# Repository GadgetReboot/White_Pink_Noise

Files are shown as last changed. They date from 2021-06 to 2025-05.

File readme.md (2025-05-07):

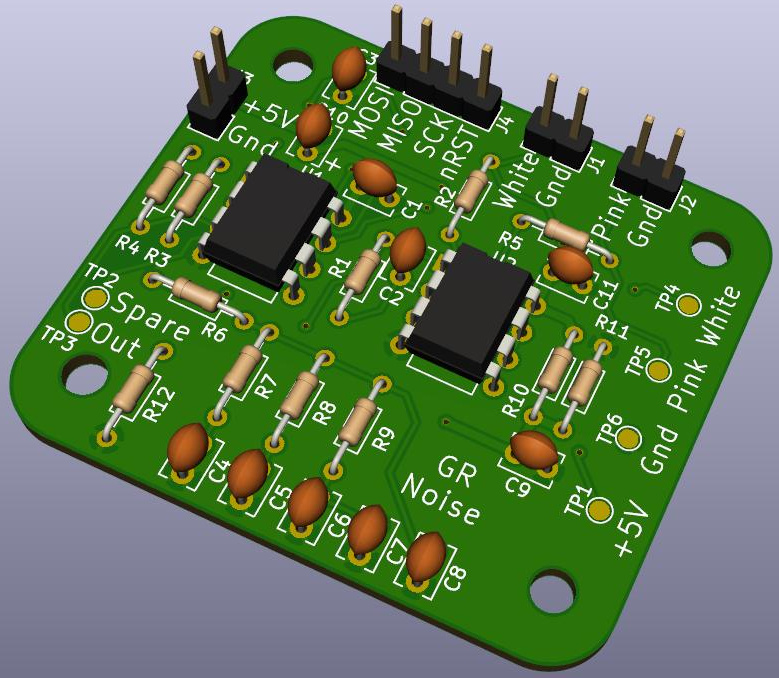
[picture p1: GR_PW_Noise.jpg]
<BR><BR><BR>
White and Pink noise generating PCB<BR>
Uses a linear feedback shift register in an ATTiny85 to generate pseudo random white noise<BR>
Then uses a -3 dB/octave low pass RC filter to convert to pink noise.<BR>
ATTiny Sketch: https://github.com/GadgetReboot/White_Noise_LFSR

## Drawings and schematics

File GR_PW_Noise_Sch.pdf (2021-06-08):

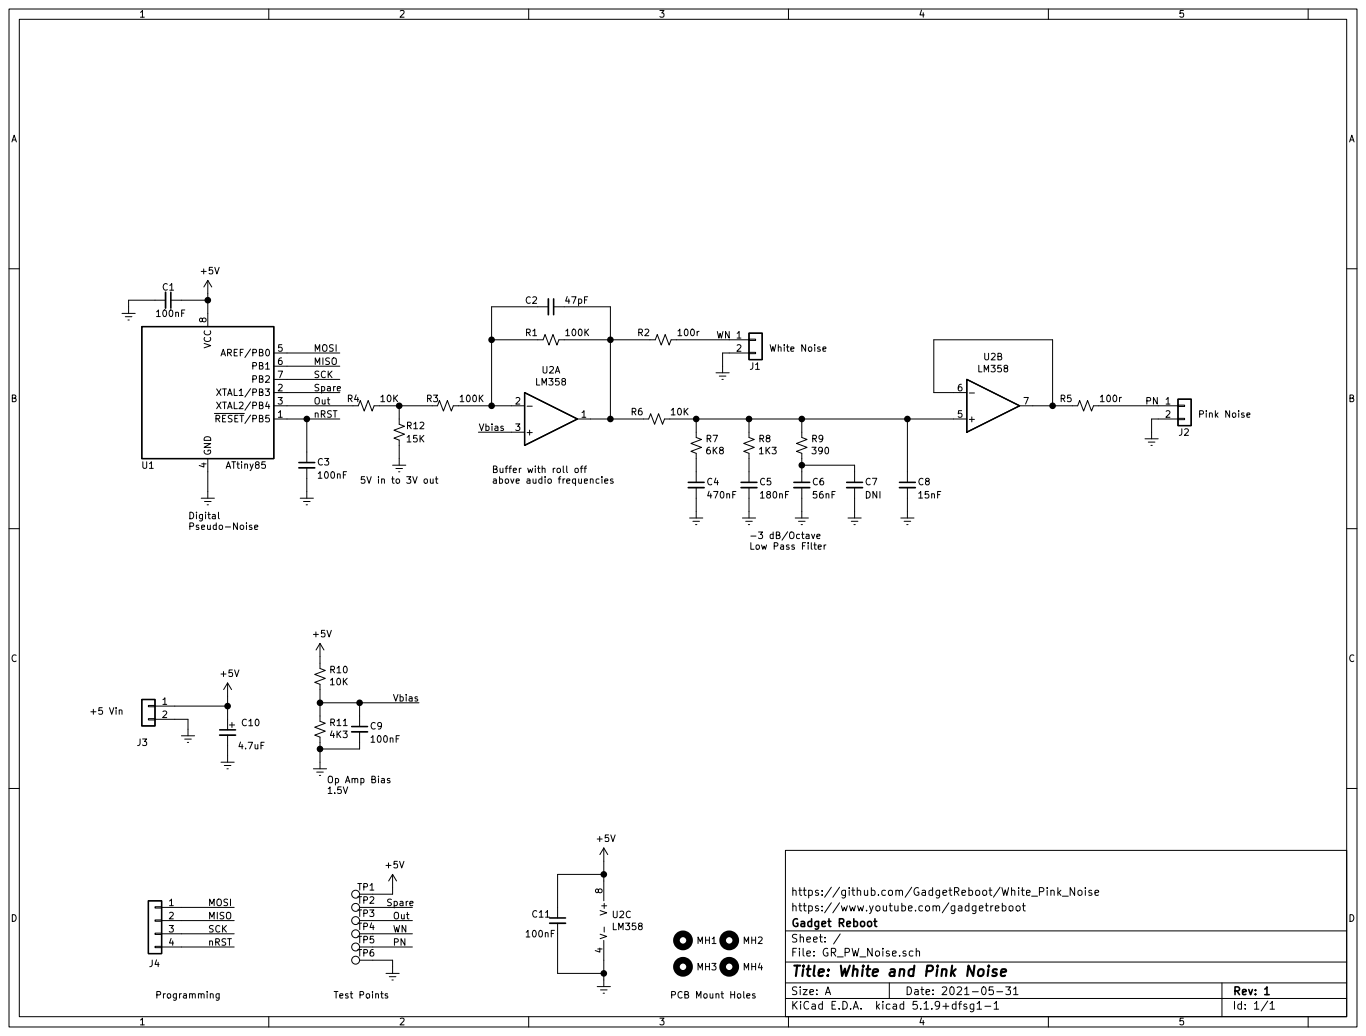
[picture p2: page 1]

PCB Mount Holes +5 Vin

https://github.com/GadgetReboot/White_Pink_Noise
https://www.youtube.com/gadgetreboot
File: GR_PW_Noise.sch Sheet: / Gadget Reboot

Id: 1/1 Title: White and Pink Noise

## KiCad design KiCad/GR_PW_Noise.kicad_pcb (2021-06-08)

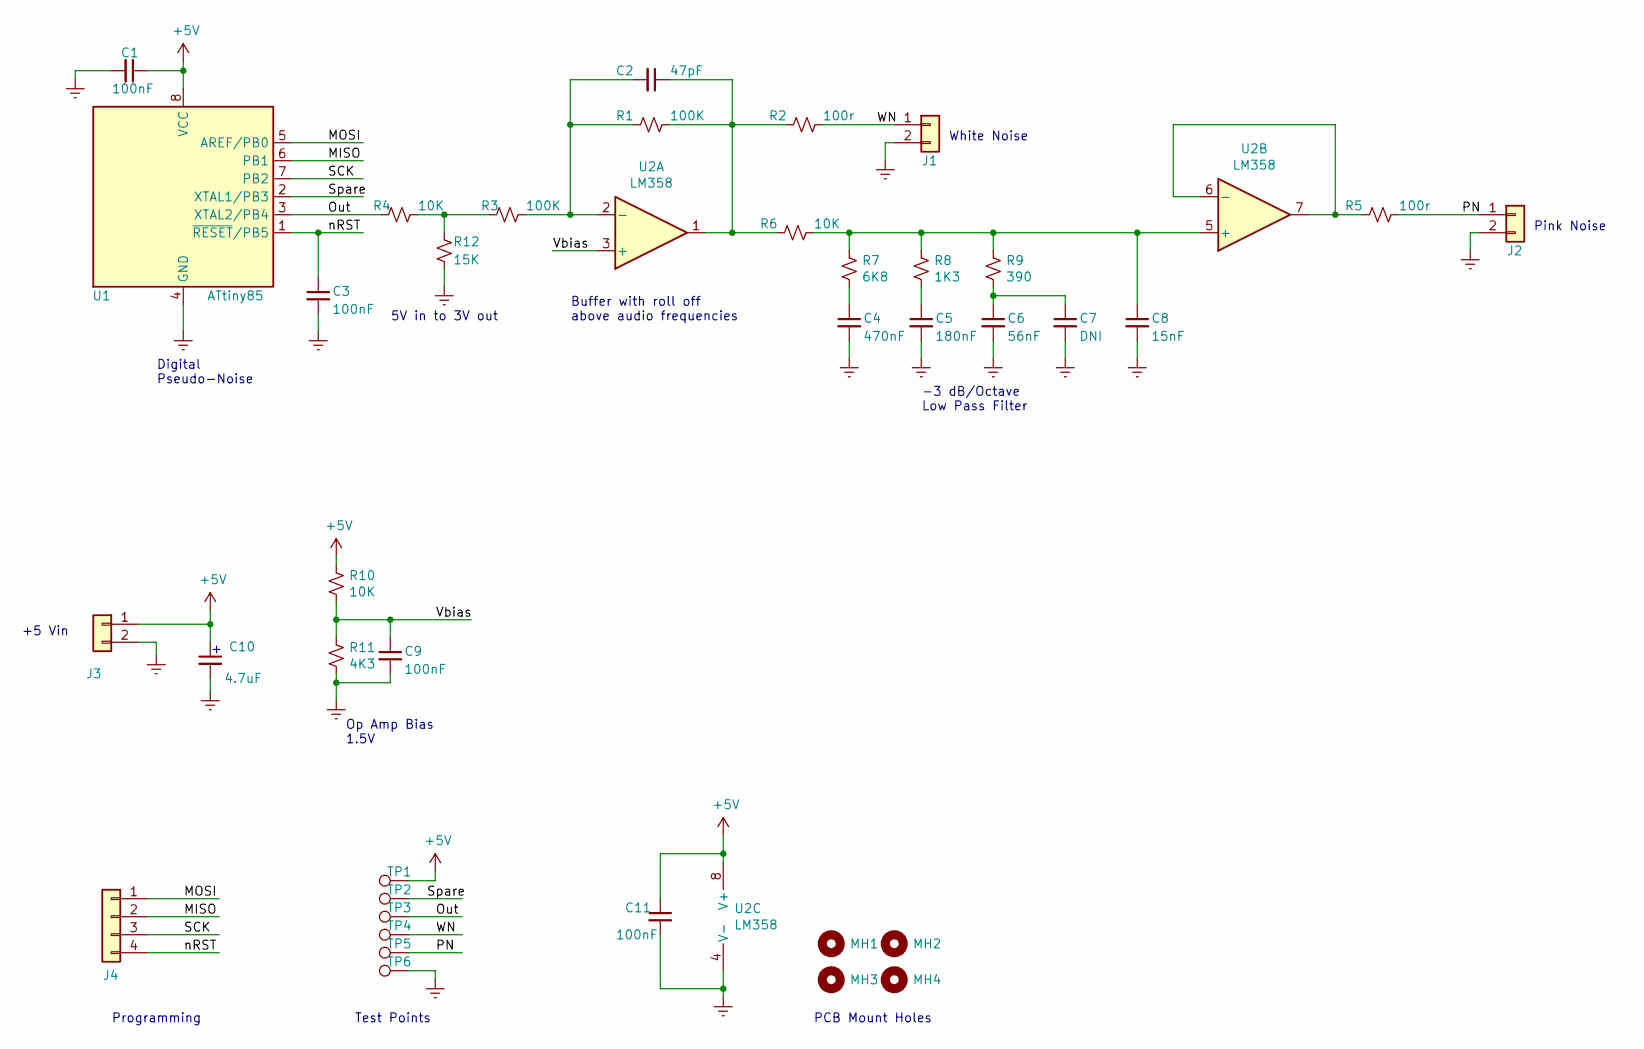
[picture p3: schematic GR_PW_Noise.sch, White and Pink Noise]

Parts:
C1, C3, C9, C11: 100nF; C_Disc_D3.8mm_W2.6mm_P2.50mm
C2: 47pF; C_Disc_D3.8mm_W2.6mm_P2.50mm
C4: 470nF; C_Disc_D3.8mm_W2.6mm_P2.50mm
C5: 180nF; C_Disc_D3.8mm_W2.6mm_P2.50mm
C6: 56nF; C_Disc_D3.8mm_W2.6mm_P2.50mm
C7: DNI; C_Disc_D3.8mm_W2.6mm_P2.50mm
C8: 15nF; C_Disc_D3.8mm_W2.6mm_P2.50mm
C10: 4.7uF; C_Disc_D3.8mm_W2.6mm_P2.50mm
J1, J2, J3: Conn_01x02; PinHeader_1x02_P2.54mm_Vertical
J4: Conn_01x04; PinHeader_1x04_P2.54mm_Vertical
MH1, MH2, MH3, MH4: MountingHole; MountingHole_3.2mm_M3
R1, R3: 100K; R_Axial_DIN0204_L3.6mm_D1.6mm_P7.62mm_Horizontal
R2, R5: 100r; R_Axial_DIN0204_L3.6mm_D1.6mm_P7.62mm_Horizontal
R4, R6, R10: 10K; R_Axial_DIN0204_L3.6mm_D1.6mm_P7.62mm_Horizontal
R7: 6K8; R_Axial_DIN0204_L3.6mm_D1.6mm_P7.62mm_Horizontal
R8: 1K3; R_Axial_DIN0204_L3.6mm_D1.6mm_P7.62mm_Horizontal
R9: 390; R_Axial_DIN0204_L3.6mm_D1.6mm_P7.62mm_Horizontal
R11: 4K3; R_Axial_DIN0204_L3.6mm_D1.6mm_P7.62mm_Horizontal
R12: 15K; R_Axial_DIN0204_L3.6mm_D1.6mm_P7.62mm_Horizontal
TP1, TP2, TP3, TP4, TP5, TP6: TestPoint; TestPoint_Pad_D1.5mm
U1: ATtiny85; DIP-8_W7.62mm
U2: LM358; DIP-8_W7.62mm

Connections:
+5V: C1.1, C10.1, C11.1, J3.1, R10.2, TP1.1, U1.8 (VCC), U2.8 (V+)
/MISO: J4.2, U1.6 (PB1)
/MOSI: J4.1, U1.5 (AREF/PB0)
/Out: R4.1, TP3.1, U1.3 (XTAL2/PB4)
/PN: J2.1, R5.2, TP5.1
/SCK: J4.3, U1.7 (PB2)
/Spare: TP2.1, U1.2 (XTAL1/PB3)
/Vbias: C9.1, R10.1, R11.2, U2.3 (+)
/WN: J1.1, R2.2, TP4.1
/nRST: C3.1, J4.4, U1.1 (~RESET~/PB5)
GNDREF: C1.2, C3.2, C4.2, C5.2, C6.2, C7.2, C8.2, C9.2, C10.2, C11.2, J1.2, J2.2, J3.2, R11.1, R12.2, TP6.1, U1.4 (GND), U2.4 (V-)
unnamed: C2.1, R1.2, R2.1, R6.1, U2.1
unnamed: C2.2, R1.1, R3.2, U2.2 (-)
unnamed: C4.1, R7.1
unnamed: C5.1, R8.1
unnamed: C6.1, C7.1, R9.1
unnamed: C8.1, R6.2, R7.2, R8.2, R9.2, U2.5 (+)
unnamed: R5.1, U2.6 (-), U2.7
unnamed: R3.1, R4.2, R12.1

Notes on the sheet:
+5 Vin
PCB Mount Holes
Pink Noise
White Noise
-3 dB/Octave Low Pass Filter
Digital Pseudo-Noise
Test Points
Programming
Op Amp Bias 1.5V
5V in to 3V out
Buffer with roll off above audio frequencies

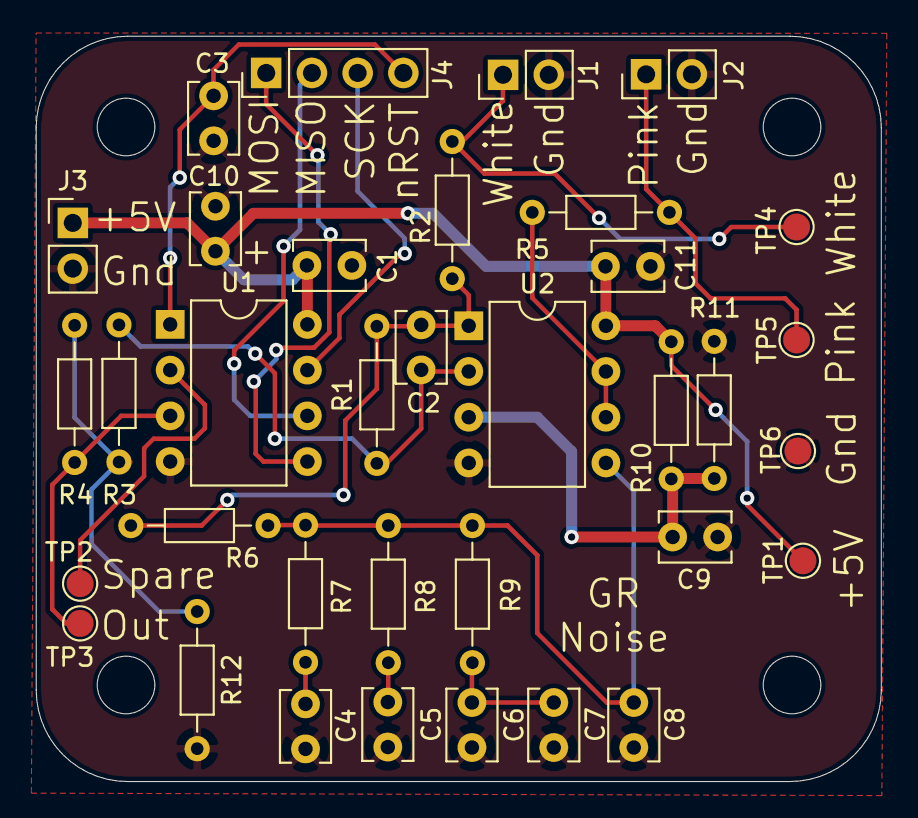
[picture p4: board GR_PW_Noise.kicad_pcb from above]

Board: 2 copper layers, 46.9 x 41.4 mm, 39 parts (0 on the bottom side), 19 nets.

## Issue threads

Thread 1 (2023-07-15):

KiCad needs .kicad_pro file

bobmc-rmm, 2023-07-15:
KiCad/  needs a project file to match the pcb and schematic.

GadgetReboot, 2023-07-17:
I added the project file

bobmc-rmm, 2023-07-18:
Thanks. Now KiCad 6.0.9 understands it.  The PCB looks good.  So does the schematic except it draws the ATTiny85 pin connections with question marks where the enclosing box should be.  "Update PCB from Schematic" works without errors or warnings.  File GW_cache.lib is missing.

I believe it can be fixed with ATTiny85-20P (DIP-8) from the KiCad symbols

GadgetReboot, 2023-07-19:
I put a lib and cache lib file in there now. I think there was a custom edit on a part so it is having trouble finding it.

Closed 2025-05-07.
